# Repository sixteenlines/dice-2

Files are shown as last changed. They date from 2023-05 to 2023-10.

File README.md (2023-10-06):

# Würfel 2.0

Projekt ESP8266 - D1 mini Matrix-Würfel mit Webserver

Umfasst eine LED Matrix, 3 Taster (davon 2 frei programmierbar) und eine einfache Website, welche leicht mit Funktionen erweitert werden kann.
Eine Möglichkeit ist der Tausch der serienmäßig verbauten 9V Batterie mit einem 3.7V Lithium Akku. Für dieses [Upgrade](#lithium-akku-upgrade) ist die Platine bereits vorbereitet.

## Repo Übersicht

### cad

Beinhaltet KiCad Projektdaten - Schaltplan und Platinenlayout.

### data

Beinhaltet Files für das Dateisystem

-   HTML Seiten
-   CSS Stylesheets
-   Icons und Bilder
-   Textdateien
    -   creds (SSID, Passwort, etc)
    -   settings (Timeoutzeiten)

### src

Quellcode

-   header_main.hpp - Macros und Header
-   main.cpp - Microcontroller Programmroutinen

## IDE & Framework

Das Projekt wurde in der [PlatformIO](https://marketplace.visualstudio.com/items?itemName=platformio.platformio-ide) Entwicklungsumgebung und mithilfe des Arduino Frameworks in Visual Studio Code realisiert. Die Erweiterung bezieht automatisch alle benötigten Libraries, welche in der [platformio.ini](https://github.com/sixteenlines/dice-2/blob/production/platformio.ini) hinterlegt sind.

In dieser werden auch die Einstellungen für den seriellen Monitor oder die entsprechenden Flags für den Programmer gesetzt.

## Dokumentation

### Einschalten

Das Einschalten des Geräts erfolgt mit dem linken Taster.

Der Controller versorgt sich über eine [Selbsthaltefunktion](https://github.com/sixteenlines/dice-2/blob/production/self-retain.jpg?raw=true) und schaltet so nach einiger Zeit (einstellbar über Webinterface) automatisch ab.

Ein manueller Reset ist über den Reset pin auf der Unterseite des Gehäuses möglich.

### AP-Mode

Beim Einschalten versucht der Controller sich mit den bekannten Daten in einem bestehendem WLAN als Client anzumelden. Misslingt dies nach 3 Versuchen, leuchtet ein roter Punkt in der Matrix auf und der Controller schaltet wieder ab.

Um die Anmeldedaten zu bearbeiten, kann das Gerät im Wifi-Manager-Modus gestartet werden. Hierzu wird beim Einschalten der mittlere Taster 5 Sekunden lang gedrückt gehalten. Der ESP hostet nun einen Access-Point und wird sichtbar als "MAGIC-DICE-SETUP".

Bei der Verbindung versucht der Controller DNS Anfragen auf ein Captive Portal umzuleiten um die Eingabemaske automatisch aufzurufen. Gelingt dies nicht, kann der Wifi-Manager über die [8.8.8.8](8.8.8.8) erreicht werden.

Nach Absenden des Formulars startet der Controller neu, bei erfolgreicher Verbindung im WLAN leuchtet ein grüner Punkt in der Matrix auf.

### Client-Mode

Wurde im Formular eine statische IP vergeben, kann man das Webinterface unter der eingestellten IP erreichen.

Wird DHCP verwendet kann die erhaltene IP über die [serielle Schnittstelle](#serielle-schnittstelle) ausgelesen werden.

Es kann nun über Betätigen des linken Tasters oder den Button im Webinterface gewürfelt werden.

Ebenso ist im Webinterface die Matrix als <div> Container widergespiegelt. Unter der Matrix kann die Farbe zum Würfeln eingestellt werden. Außerdem können individuelle LEDs angeklickt werden um sie in der gewählten Farbe aufleuchten zu lassen. Wiederholtes klicken schaltet sie wieder aus.

Über das Einstellungsmenü kann die Dauer der Beleuchtung und die Zeit bis der Controller abschaltet, konfiguriert werden.

Ebenso findet sich hier der WiFi-Manager wieder, falls in ein anderes Netzwerk gewechselt werden soll. Nach Eingabe muss jedoch der Controller erst [neu gestartet](#einschalten) werden.

### Offline-Mode

Wird beim Einschalten der rechte Taster bis zum Aufleuchten eines blauen Punktes gehalten, startet das Gerät im Offline-Modus. Hierbei wird das Wifi-Modul abgeschaltet um die Akkulaufzeit erheblich zu erhöhen. In diesem Modus ist jedoch lediglich die Würfel-Funktion verfügbar.

### Serielle Schnittstelle

Verbindet man das Gerät über USB, können mithilfe eines Terminalprogramms Debugging-Informationen und von DHCP erhaltene IP-Adressen ausgelesen werden.

Der Controller sendet standardmäßig mit einer Baudrate von 115200.

Zur Fehlerdiagnose ist ratsam, den Controller zu verbinden, die entsprechende serielle Schnittstelle zu öffnen und zunächst einen [reset](#einschalten) durchzuführen.

Es werden nun sämtliche Schritte des Bootvorgangs gespiegelt. Außerdem werden Anfragen an den Webserver gelogt.

## Lithium Akku Upgrade

### Übersicht und Stückliste

Um das Gerät mit einem wiederaufladbarem Akku auszustatten müssen einige zusätzliche Teile bezogen werden. In Klammern jeweils aufgeführt, ist der verwendete Footprint auf der Platine oder eine Teileempfehlung.

1x 2.0 USB-C Port (GCT-USB4085)

1x 3.7V Lithium Akku (LiPo 103450 - 51mm x 39mm x 10mm)

1x LiPo Laderegler mit DC-DC Converter 3.7V - 5V

1x Drahtbrücke (0.6mm)

1x Klebestreifen für Akku ([iFixit Klebestreifen](https://store.ifixit.de/products/stretch-release-battery-adhesive))

Optional:

1x JST-PH2 Header oder JST-XH2 oder JST-EH2 je nach Akku/Hersteller (siehe Datenblatt)

Die bereits verbaute Steckleiste J1 ist ausgelegt auf ein [kompaktes Modul](https://de.aliexpress.com/item/33034500618.html) mit DC-DC Wandler und Laderegler. Wird von diesem abgewichen, ist auf eine [korrekte Pinbelegung](https://github.com/sixteenlines/dice-2/blob/production/cad/screenshot/dcdc_charge_header.jpg?raw=true) nach Schaltplan zu achten. Auch ist die korrekte Polarität beim direkten Verlöten der Akku Litzen, oder Bestücken des JST-Headers zu prüfen.

### Arbeitsschritte:

1. Öffnen des Gehäuses (Schraubendreher) und Entfernen der 9V Blockbatterie (Seitenschneider)

2. Entfernen des TSR1-2450 (U2)

3. Bestücken und Verlöten von Drahtbrücke B1 (Pin 1 - Pin 3 von U2)

4. Bestücken und Verlöten von THT 2.0 USB Connector

5. Bestücken und Verlöten des optionalen JST-Headers oder verlöten der Akku Litzen

6. Aufsetzen und Verlöten des DCDC-Charge Controller Moduls

7. USB Ladegerät anschließen und verifizieren, dass die Charge LED des eingesetzten Moduls aufleuchtet.

8. Akku mit Klebestreifen an die Stelle der alten 9V Batterie verkleben und Gehäuse wieder schließen.

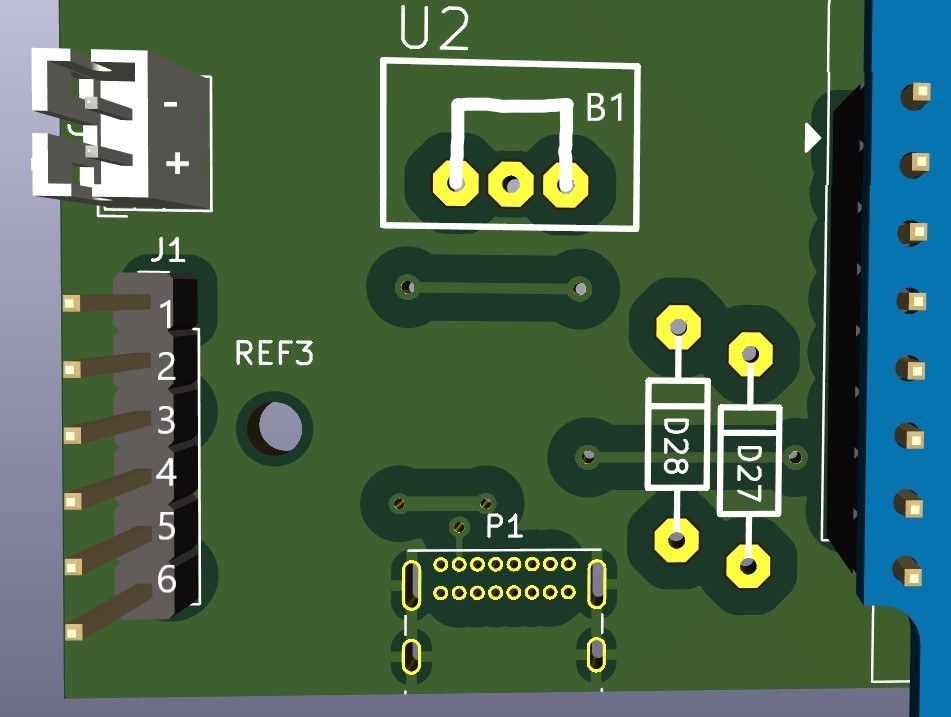
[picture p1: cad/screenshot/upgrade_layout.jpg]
Übersicht


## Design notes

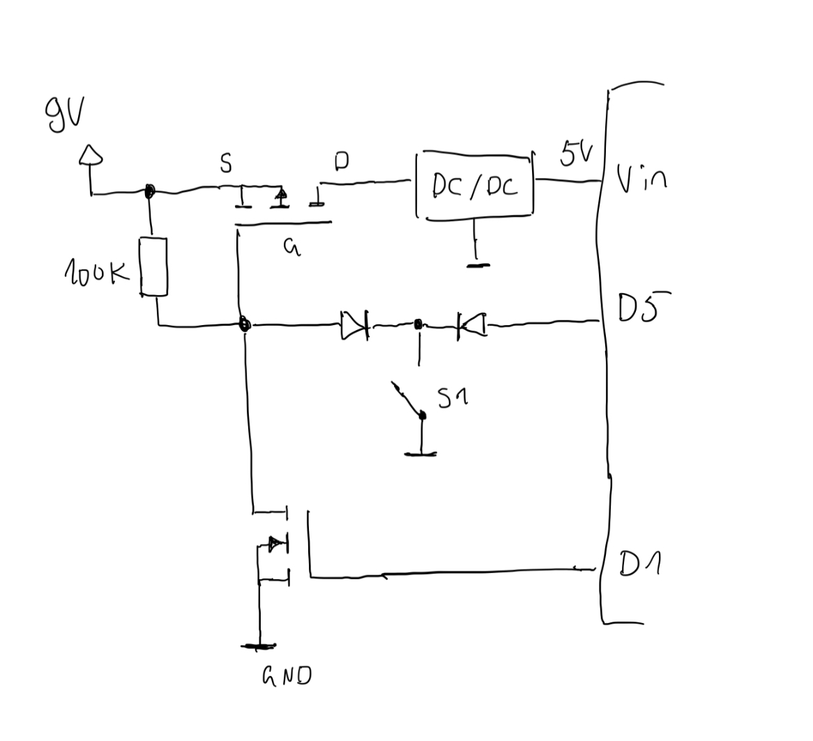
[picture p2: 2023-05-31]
self-retain.jpg

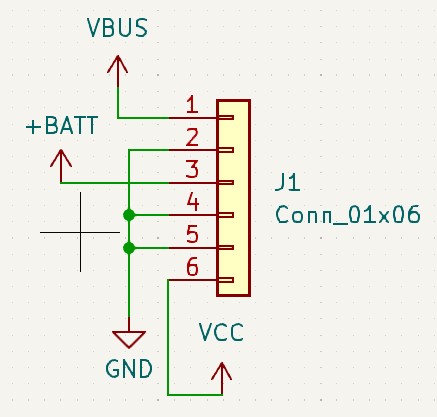
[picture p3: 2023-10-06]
cad/screenshot/dcdc_charge_header.jpg

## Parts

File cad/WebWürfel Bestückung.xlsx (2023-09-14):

Item | Qty | Reference(s) | Value | LibPart | Footprint | Comment
1 | 1 | BAT1 | 9V | D1Mini_Wuerfel_aktuell-eagle-import:BATTERIE_2 | D1Mini_Wuerfel_aktuell:BATTERIE_2
2 | 25 | D1-D25 | WS2812B | D1Mini_Wuerfel_aktuell-eagle-import:WS2812B_9 | D1Mini_Wuerfel_aktuell:WS2812B_9
3 | 1 | D26 | 1N4148 | D1Mini_Wuerfel_aktuell-eagle-import:1N4148_1 | D1Mini_Wuerfel_aktuell:DO35_1
4 | 1 | D27 | 1N5817 | D1Mini_Wuerfel_aktuell-eagle-import:1N5817_40 | D1Mini_Wuerfel_aktuell:DO41_40 | Alternativ 1N4148
5 | 1 | D28 | 1N5817 | D1Mini_Wuerfel_aktuell-eagle-import:1N5817_41 | D1Mini_Wuerfel_aktuell:DO41_41 | Alternativ 1N4148
6 | 1 | K1 | 1x03 | D1Mini_Wuerfel_aktuell-eagle-import:K1X03_BUCHSE_8 | D1Mini_Wuerfel_aktuell:1X03_BUCHSE_8
7 | 1 | R1_SMT1 | 100K | Device:R | Resistor_SMD:R_1206_3216Metric | R1 als SMD oder THT Widerstand, nicht beide
8 | 1 | R1_THT1 | 100K | D1Mini_Wuerfel_aktuell-eagle-import:R_KOHLE_1M_0207_37 | D1Mini_Wuerfel_aktuell:0207_37 | R1 als SMD oder THT Widerstand, nicht beide
9 | 1 | R2 | 330 | D1Mini_Wuerfel_aktuell-eagle-import:R_KOHLE_330-OHM_0207_44 | D1Mini_Wuerfel_aktuell:0207_44
10 | 3 | S1, S2, S3 | SPST | D1Mini_Wuerfel_aktuell-eagle-import:1254.1017_DRUCKTASTER_12X12MM_34 | D1Mini_Wuerfel_aktuell:1254.1017_DRUCKTASTER_34
11 | 1 | T1 | IRF9952 | D1Mini_Wuerfel_aktuell-eagle-import:IRF9952_39 | D1Mini_Wuerfel_aktuell:SO8_SOT96-1_39 | T1 oder T2+T3, nicht beide
12 | 1 | T2 | FDN337N | D1Mini_Wuerfel_aktuell-eagle-import:FDN337N_42 | D1Mini_Wuerfel_aktuell:SOT-23_3_42 | T1 oder T2+T3, nicht beide
13 | 1 | T3 | IRLML9301 | D1Mini_Wuerfel_aktuell-eagle-import:IRLML9301TRPBF_43 | D1Mini_Wuerfel_aktuell:SOT-23_3_43 | T1 oder T2+T3, nicht beide
14 | 1 | U1 | D1_mini | MCU_Module:WeMos_D1_mini | Module:WEMOS_D1_mini_light
15 | 1 | U2 | TSR1-2450 | D1Mini_Wuerfel_aktuell-eagle-import:TSR1-2450_0 | D1Mini_Wuerfel_aktuell:TRACO-TSR1-24_0

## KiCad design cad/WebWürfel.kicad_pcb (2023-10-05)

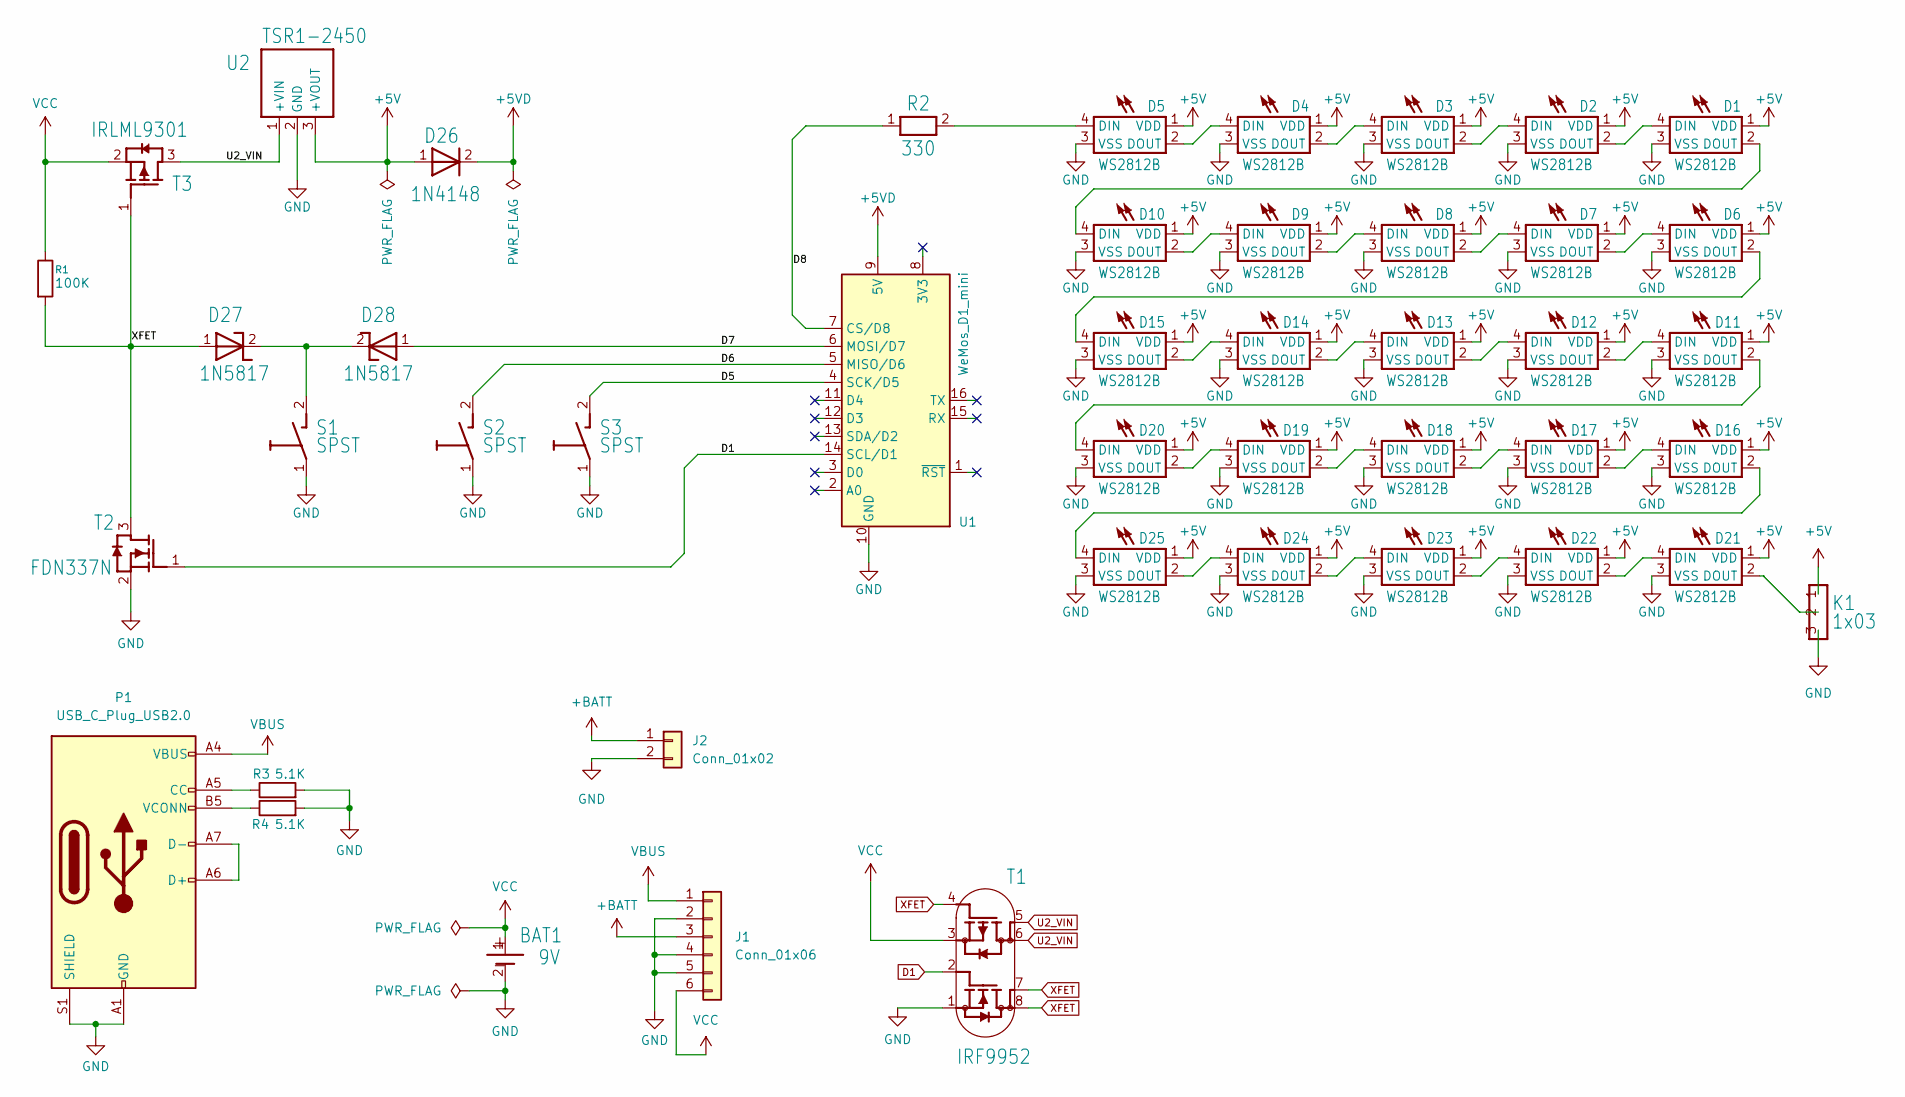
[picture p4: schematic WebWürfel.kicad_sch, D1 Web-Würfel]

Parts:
BAT1: 9V; BATTERIE_2
D1, D2, D3, D4, D5, D6, D7, D8, D9, D10, D11, D12, D13, D14, D15, D16, D17, D18, D19, D20, D21, D22, D23, D24, D25: WS2812B; WS2812B_9
D26: 1N4148; DO35_1
D27: 1N5817; DO41_40
D28: 1N5817; DO41_41
J1: Conn_01x06; PinHeader_1x06_P2.54mm_Vertical
J2: Conn_01x02; JST_PH_B2B-PH-K_1x02_P2.00mm_Vertical
K1: 1x03; 1X03_BUCHSE_8
P1: USB_C_Plug_USB2.0; USB_C_Receptacle_GCT_USB4085
R1: 100K; R_1206_3216Metric
R2: 330; 0207_44
R3, R4: 5.1K; R_1206_3216Metric
S1, S2, S3: SPST; 1254.1017_DRUCKTASTER_34
T1: IRF9952; SO8_SOT96-1_39
T2: FDN337N; SOT-23_3_42
T3: IRLML9301; SOT-23_3_43
U1: WeMos_D1_mini; WEMOS_D1_mini_light
U2: TSR1-2450; TRACO-TSR1-24_0

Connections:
+5V: D1.1 (VDD), D2.1 (VDD), D3.1 (VDD), D4.1 (VDD), D5.1 (VDD), D6.1 (VDD), D7.1 (VDD), D8.1 (VDD), D9.1 (VDD), D10.1 (VDD), D11.1 (VDD), D12.1 (VDD), D13.1 (VDD), D14.1 (VDD), D15.1 (VDD), D16.1 (VDD), D17.1 (VDD), D18.1 (VDD), D19.1 (VDD), D20.1 (VDD), D21.1 (VDD), D22.1 (VDD), D23.1 (VDD), D24.1 (VDD), D25.1 (VDD), D26.1, K1.1, U2.3 (+VOUT)
+5VD: D26.2, U1.9 (5V)
+BATT: J1.3 (BAT), J2.1
/D5: S3.2, U1.4 (SCK/D5)
/D6: S2.2, U1.5 (MISO/D6)
/D7: D28.1, U1.6 (MOSI/D7)
/D8: R2.1, U1.7 (CS/D8)
D1: T1.2, T2.1, U1.14 (SCL/D1)
GND: BAT1.2, D1.3 (VSS), D2.3 (VSS), D3.3 (VSS), D4.3 (VSS), D5.3 (VSS), D6.3 (VSS), D7.3 (VSS), D8.3 (VSS), D9.3 (VSS), D10.3 (VSS), D11.3 (VSS), D12.3 (VSS), D13.3 (VSS), D14.3 (VSS), D15.3 (VSS), D16.3 (VSS), D17.3 (VSS), D18.3 (VSS), D19.3 (VSS), D20.3 (VSS), D21.3 (VSS), D22.3 (VSS), D23.3 (VSS), D24.3 (VSS), D25.3 (VSS), J1.2 (GND), J1.4 (GND), J1.5 (GND), J2.2, K1.3, P1.A1 (GND), P1.A12 (GND), P1.B1 (GND), P1.B12 (GND), P1.S1 (SHIELD), R3.2, R4.2, S1.1, S2.1, S3.1, T1.1, T2.2, U1.10 (GND), U2.2 (GND)
unnamed: D1.4 (DIN), D2.2 (DOUT)
unnamed: D1.2 (DOUT), D10.4 (DIN)
unnamed: D2.4 (DIN), D3.2 (DOUT)
unnamed: D3.4 (DIN), D4.2 (DOUT)
unnamed: D4.4 (DIN), D5.2 (DOUT)
unnamed: D5.4 (DIN), R2.2
unnamed: D6.4 (DIN), D7.2 (DOUT)
unnamed: D7.4 (DIN), D8.2 (DOUT)
unnamed: D8.4 (DIN), D9.2 (DOUT)
unnamed: D9.4 (DIN), D10.2 (DOUT)
unnamed: D11.4 (DIN), D12.2 (DOUT)
unnamed: D11.2 (DOUT), D20.4 (DIN)
unnamed: D12.4 (DIN), D13.2 (DOUT)
unnamed: D13.4 (DIN), D14.2 (DOUT)
unnamed: D14.4 (DIN), D15.2 (DOUT)
unnamed: D6.2 (DOUT), D15.4 (DIN)
unnamed: D16.4 (DIN), D17.2 (DOUT)
unnamed: D16.2 (DOUT), D25.4 (DIN)
unnamed: D17.4 (DIN), D18.2 (DOUT)
unnamed: D18.4 (DIN), D19.2 (DOUT)
unnamed: D19.4 (DIN), D20.2 (DOUT)
unnamed: D21.4 (DIN), D22.2 (DOUT)
unnamed: D21.2 (DOUT), K1.2
unnamed: D22.4 (DIN), D23.2 (DOUT)
unnamed: D23.4 (DIN), D24.2 (DOUT)
unnamed: D24.4 (DIN), D25.2 (DOUT)
unnamed: D27.2, D28.2, S1.2
unnamed: P1.A5 (CC), R3.1
unnamed: P1.A6 (D+), P1.A7 (D-)
unnamed: P1.B5 (VCONN), R4.1
U2_VIN: T1.5, T1.6, T3.3, U2.1 (+VIN)
VBUS: J1.1 (VIN), P1.A4 (VBUS), P1.A9 (VBUS), P1.B4 (VBUS), P1.B9 (VBUS)
VCC: BAT1.1, J1.6 (VOUT), R1.1, T1.3, T3.2
XFET: D27.1, R1.2, T1.4, T1.7, T1.8, T2.3, T3.1

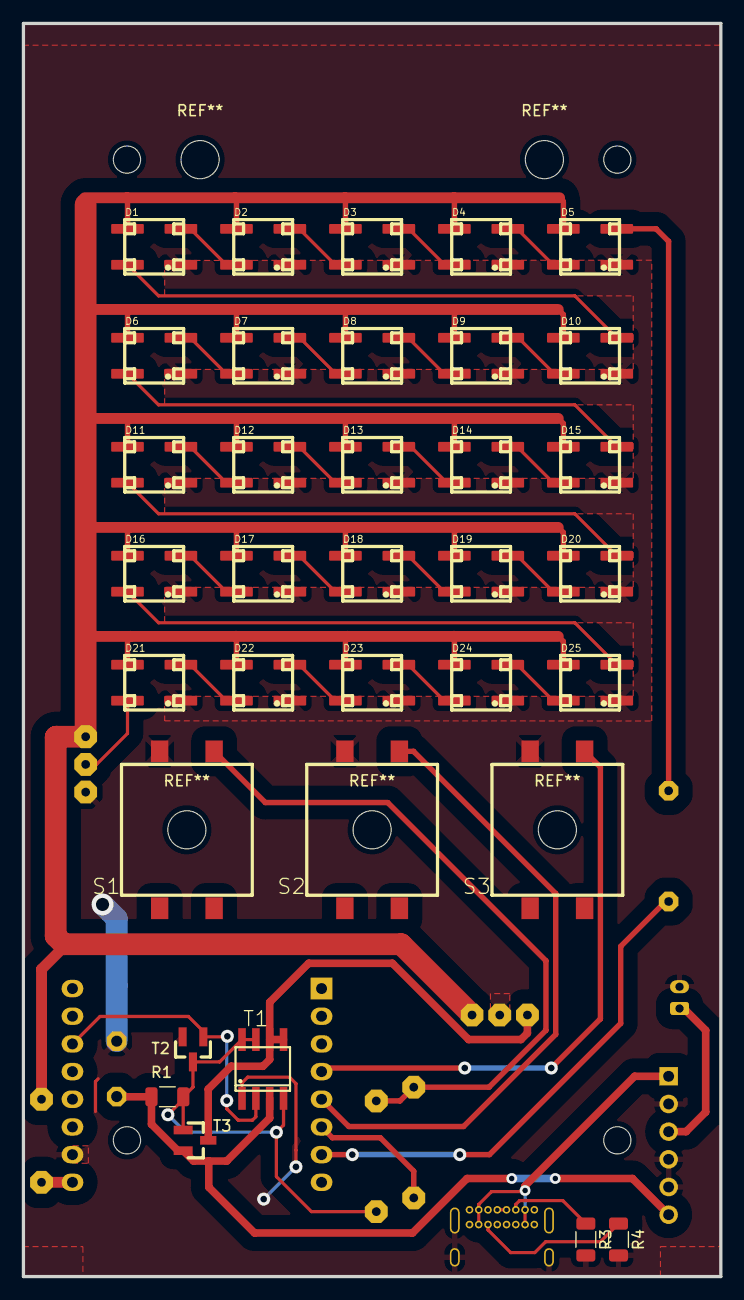
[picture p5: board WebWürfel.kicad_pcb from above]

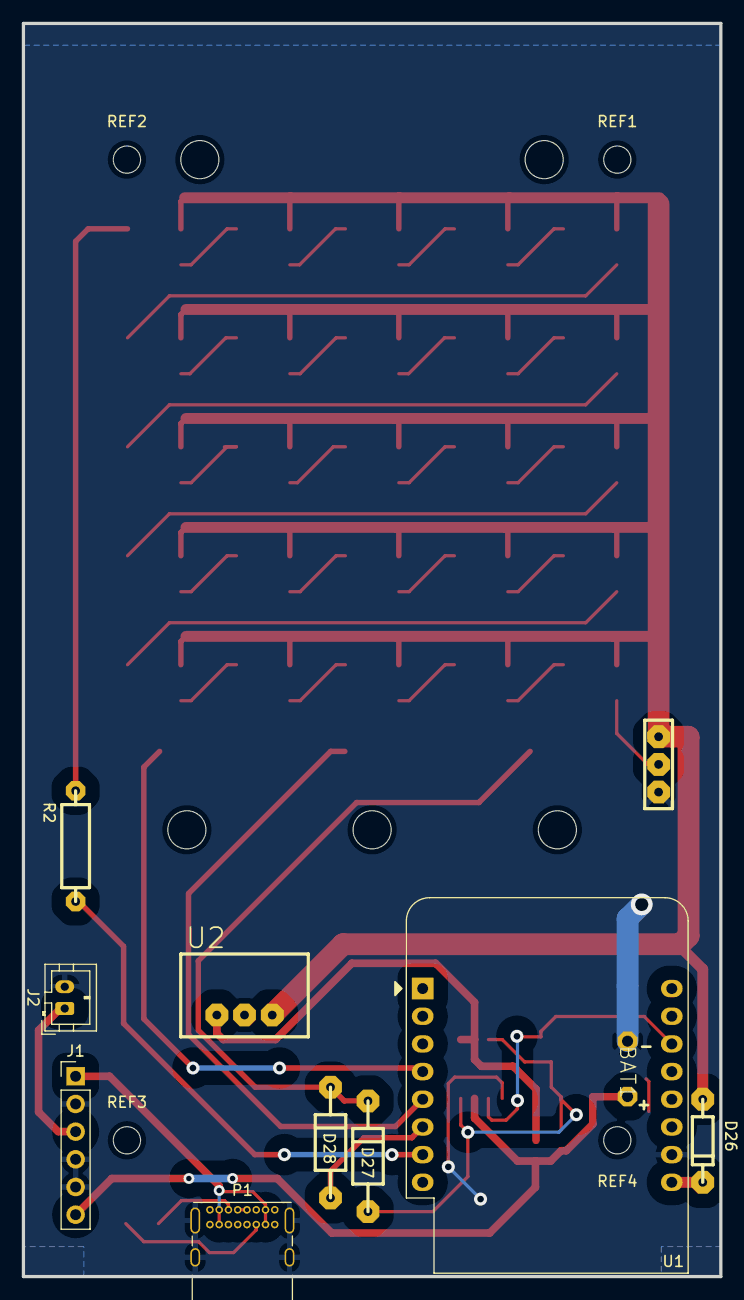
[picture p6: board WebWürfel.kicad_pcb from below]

Board: 2 copper layers, 64.0 x 115.0 mm, 49 parts (15 on the bottom side), 43 nets.

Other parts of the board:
REF1, REF2, REF3, REF4: MountingHole_2.5mm

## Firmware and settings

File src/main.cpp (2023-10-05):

#include <webserver.hpp>
#include <filesystem.hpp>
#include <ledmatrix.hpp>
#include <macros.hpp>
#include <Arduino.h>

/* external vars */
extern uint8_t dieRollResult;

extern bool rollRequested;
extern bool sleepRequested;
extern bool managerRequested;

extern uint8_t diceRed;
extern uint8_t diceGreen;
extern uint8_t diceBlue;

extern unsigned long lastActionTime;

extern unsigned long deep_sleep;
extern unsigned long led_sleep;
extern unsigned int roll_delay;

/* function declarations */
void sleep();
void initIO();
void rollDice();
void prerollDice();

/* timer var */
unsigned long currentTime = 0;

/*###################################### SETUP ##############################*/
void setup()
{
    initIO();
    initFS();
    initSettings();
    initLeds();

    if (initWifi())
    {
        Serial.println("[\e[0;32m  OK  \e[0;37m] Initializing WiFi");
    }
    else
    {
        if (sleepRequested)
        {
            Serial.println("[\e[0;31mFAILED\e[0;37m] Initializing WiFi");
            Serial.println(INDENT + "Going to Sleep");
        }
        else
        {
            Serial.println("[\e[0;32m  OK  \e[0;37m] Offline Mode");
        }
    }
}

/*###################################### MAIN ###############################*/
void loop()
{
    if (managerRequested)
    {
        dnsNext();
    }
    else
    {
        if (sleepRequested)
        {
            sleep();
        }
        currentTime = millis();

        if (!(digitalRead(BTN0_PIN)))
        {
            dieRollResult = random(6) + 1;
            rollRequested = true;
        }

        if (rollRequested)
        {
            rollDice();
        }
        if (currentTime - lastActionTime >= deep_sleep)
        {
            sleep();
        }
        if (currentTime - lastActionTime >= led_sleep)
        {
            hideLEDS();
        }
    }
}

void initIO()
{
    Serial.begin(115200);
    Serial.println();
    pinMode(BTN0_PIN, INPUT_PULLUP); // used for rolling manually
    pinMode(BTN1_PIN, INPUT_PULLUP); // hold on boot for wifi manager
    pinMode(BTN2_PIN, INPUT_PULLUP); // free
    pinMode(D4, OUTPUT);
    pinMode(RETENTION_PIN, OUTPUT);
    pinMode(STATUSLED_PIN, OUTPUT); // can be used to control onboard led
    digitalWrite(RETENTION_PIN, HIGH);
    digitalWrite(D4, HIGH);
    Serial.println("[\e[0;32m  OK  \e[0;37m] Initializing system I/O");
}

// prints a random die roll to the matrix
void prerollDice()
{
    static uint8_t lastPreroll = 0;
    uint8_t preroll = random(6) + 1;
    while (preroll == lastPreroll)
    {
        preroll = random(6) + 1;
    }
    lastPreroll = preroll;
    printPattern(preroll, diceRed, diceGreen, diceBlue);
}

void rollDice()
{
    // rolling a few times to simulate a real die
    static unsigned short prerollDisplayDuration = 50;

    if (prerollDisplayDuration > roll_delay)
    {
        if (currentTime - lastActionTime >= (roll_delay + 100))
        {
            printPattern(dieRollResult, diceRed, diceGreen, diceBlue);
            rollRequested = false;
            prerollDisplayDuration = 50;
        }
    }
    else if (currentTime - lastActionTime >= prerollDisplayDuration)
    {
        prerollDice();
        lastActionTime = currentTime;
        prerollDisplayDuration += 50;
    }
}

// pulls self-retention pin low, device turns off
void sleep()
{
    digitalWrite(RETENTION_PIN, LOW);
}

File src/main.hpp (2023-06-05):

#include <vector>
#include <Adafruit_NeoPixel.h>
#include <ESP8266WiFi.h>
#include <ESPAsyncWebServer.h>
#include <ESPAsyncTCP.h>
#include <LittleFS.h>
#include <DNSServer.h>
#include <Arduino.h>

/* Pins */
#define STATUSLED_PIN D4
#define RETENTION_PIN D1
#define LEDS_PIN D8
#define BTN0_PIN D6
#define BTN1_PIN D7
#define BTN2_PIN D5

/* credential offset macros */
#define _SSID 0
#define _PASS 1
#define _IPAD 2
#define _GATE 3
#define _SUBN 4

/* LED-pattern macros */
#define BIGDOT 7
#define LOADING 8

/* Timer constants */
const unsigned long DEEP_SLEEP = 180000;
const unsigned long LIGHTS_OFF = 20000;

/* Endpoint params index */
const char *PARAM_R = "r";
const char *PARAM_G = "g";
const char *PARAM_B = "b";
const char *PARAM_LED = "led";
const char *PARAM_RESULT = "result";

/* Endpoint params manager */
const char *PARAM_INPUT_0 = "ssid";
const char *PARAM_INPUT_1 = "pass";
const char *PARAM_INPUT_2 = "ip";
const char *PARAM_INPUT_3 = "gateway";
const char *PARAM_INPUT_4 = "subnet";
const String MANAGER = "http://8.8.8.8";

/* File paths to storage */
const std::vector<String> paths = {
    "/ssid.txt",
    "/password.txt",
    "/ip.txt",
    "/gateway.txt",
    "/subnet.txt"};

/* LED-pattern vector */
const std::vector<std::vector<int>> patterns = {
    {},                                // symbol 0
    {12},                              // symbol 1
    {4, 20},                           // symbol 2
    {4, 12, 20},                       // symbol 3
    {0, 4, 20, 24},                    // symbol 4
    {0, 4, 12, 20, 24},                // symbol 5
    {0, 4, 10, 14, 20, 24},            // symbol 6
    {6, 7, 8, 11, 12, 13, 16, 17, 18}, // BIGDOT 7
    {0, 1, 2, 3, 4, 9, 14,
     19, 24, 23, 22, 21,
     20, 15, 10, 5} // LOADING 8
};

const uint8_t loading[] = {0, 1, 2, 3, 4, 9, 14,
                           19, 24, 23, 22, 21,
                           20, 15, 10, 5};

/* function declarations */
void prerolldice(void);
void marius(void);
bool initWifi(void);
bool clientSetup(void);
void managerSetup(void);
void initIO(void);
void hostManager(void);
void hostIndex(void);
bool loadCredentials(void);
void printPattern(uint8_t pattern);
void printPattern(uint8_t pattern, uint8_t r, uint8_t g, uint8_t b);
void setLED(uint8_t num, uint8_t r, uint8_t g, uint8_t b);
void clearLED(uint8_t num);
void initFS(void);
bool handleFileRequest(AsyncWebServerRequest *request, String path);
void writeFile(const String path, const char *message);
String readFile(const String path);

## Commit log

2023-05-27 Individual LED switching support TEST
2023-05-27 deep sleep moved to main loop to prevent crashing
    [main.cpp]
2023-06-01 not working manager but css
    [main.cpp, main.hpp]
2023-06-02 not working led lags
    [main.cpp, main.hpp]
2023-06-02 Happy loading leds
2023-06-05 Changed neopixel to grb for board layout
2023-06-05 Led number position adjusted for final layout
2023-06-06 reordered functions and implemented LED objects
2023-06-06 updated pinout for production pcb
2023-06-06 updated led color profile
2023-06-06 cleaned up led functions
2023-06-07 fixes for webpage and handling of settings
    [main.cpp]
2023-06-20 settings sync working + safari href fix
    [main.cpp]
2023-06-29 minor fixes and added comments
    [main.cpp]
2023-07-18 fixed accidental removal of file write
    [main.cpp]
2023-07-20 adding kicad files
    [D1Mini_Wuerfel_aktuell.kicad_pcb, D1Mini_Wuerfel_aktuell.kicad_sch]
2023-07-21 readme proofreading
    [D1Mini_Wuerfel_aktuell.kicad_pcb]
2023-09-08 updated cad
    [D1Mini_Wuerfel_aktuell-B_Cu.gbr, D1Mini_Wuerfel_aktuell-B_Mask.gbr, D1Mini_Wuerfel_aktuell-B_Paste.gbr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]
2023-09-13 changed buttons to internal pullups
2023-09-14 old led grid
    [WebWürfel Bestückung.xlsx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]
2023-09-15 rotated d1 mini by 90°
    [WebWürfel.kicad_pcb, WebWürfel.kicad_sch]
2023-09-18 fixed vars and added offline mode
    [filesystem.cpp, macros.hpp, main.cpp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]
2023-09-18 die roll glitch fix
    [main.cpp]
2023-09-18 half brightness leds for longer battery life
2023-10-05 kicad update battery
    [WebWürfel.kicad_pcb, WebWürfel.kicad_sch]
2023-10-06 LiPo Anleitung
